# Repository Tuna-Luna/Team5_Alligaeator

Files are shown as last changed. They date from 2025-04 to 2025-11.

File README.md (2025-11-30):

# Alligaeator
## Capstone Design Project Team 5

## Overview
Alligaeator is an AI-powered nutrition assistant that combines a YOLOv5 food detector, an Arduino-driven load-cell scale, and an Android companion app. The system identifies a dish from a live webcam feed, measures its weight automatically, and reports calorie and macronutrient estimates through a mobile UI.

Design Overview

## Key Features
- Real-time food recognition powered by a custom-trained YOLOv5 model (`src/project/best2.pt`).
- Automated weight capture through an MG995 servo, HX711 load sensor, and Arduino firmware (`src/arduino/arduino.ino`).
- Nutrition lookup using per-gram macro data stored in `src/project/foods.json`, enabling instant calorie, carb, protein, and fat estimates.
- REST API built with FastAPI so the Android client (`src/application/MyApplication3.zip`) can request detections and control the hardware.
- Mechanical components and assembly-ready G-code/STL files (`3D/`) for the smart plate enclosure.

## Repository Tour
- `src/project/` – YOLOv5 inference utilities (`detect_api_final.py`), the FastAPI service (`android_respond_test.py`), dataset configs (`data.yaml`, `data2.yaml`), nutrition tables, and sample images (`food/`).
- `src/arduino/` – Arduino sketch that drives the MG995 servo, HX711 load cell, and optional I2C LCD for real-time weight display.
- `src/application/MyApplication3.zip` – Android Studio project that consumes the HTTP API and displays the nutrition report.
- `3D/` – Printable hinge, upper/lower plate, and enclosure parts in `.gcode`, `.3mf`, and `.stl` formats.
- `dataset.tar.gz` – Packaged training dataset used for YOLOv5 fine-tuning.
- `assets/` – Images and GIFs referenced in this README.

## System Architecture
The workflow starts with a webcam feed piped to a YOLOv5 model running on a Raspberry Pi or PC. Detected food classes are combined with real-time weight readings from the Arduino, and the FastAPI service exposes the combined nutrition information for the Android app.

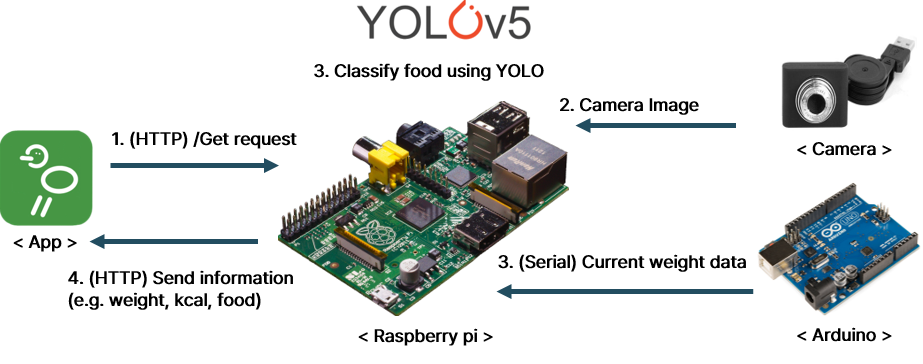
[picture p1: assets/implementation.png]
Implementation Overview


## Hardware System
The hardware layer mounts a plate on a load cell amplified by an HX711 module while an MG995 servo clears or rotates the plate between servings (`src/arduino/arduino.ino`). The Arduino publishes weight readings over serial (9600 baud) and accepts simple text commands (`LEFT`, `RIGHT`, `STOP`), which the FastAPI server issues when the Android app triggers plate rotation or resets the tare.

## Software Pipeline
### YOLOv5 Detector
`detect_api_final.py` wraps YOLOv5’s `DetectMultiBackend`, handles webcam capture, writes snapshots to `./captures/`, and returns the top detection (default `max_det=1`). Sample stills for offline testing live under `src/project/food/`.

### Nutrition + API Layer
`android_respond_test.py` hosts a FastAPI service that:
- calls the detector with `best2.pt` to classify food from either `source=0` (webcam) or the static `food/` images,
- reads the current weight from the Arduino over `/dev/ttyACM0`,
- multiplies the weight by per-gram values stored in `foods.json`, and
- returns the totals to the Android app. The same service exposes `/rotate`, `/finish`, and `/init` endpoints for servo control.

### Android Client
The Android Studio project (`MyApplication3.zip`) hooks into the FastAPI endpoints, displays detection results, and records the calorie log directly on the phone.

### 3D Printable Enclosure
All mechanical components needed for the smart plate—upper/lower shell, hinge variants, and mounting plates—are available in the `3D/` folder as ready-to-print `.gcode` or editable `.3mf`/`.stl` files to reproduce the physical housing.

## Dataset & Training Notes
`data2.yaml` defines 15 labeled food categories (`bean sprouts`, `beef`, `chicken`, `egg`, `pork`, `garlic`, `green onion`, `kimchi`, `onion`, `potato`, `spam`, `banana`, `sweet potato`, `cherry tomato`, `chicken breast`). Training/validation images are expected in `../train/images` and `../valid/images`, respectively, and the archived dataset (`dataset.tar.gz`) mirrors those splits. Model fine-tuning follows the standard YOLOv5 workflow

## Demo
Watch the final demo to see the full workflow in action.

Final Demo

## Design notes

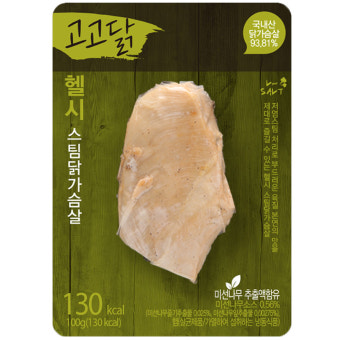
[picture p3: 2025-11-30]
src/project/food/cb2.jpg

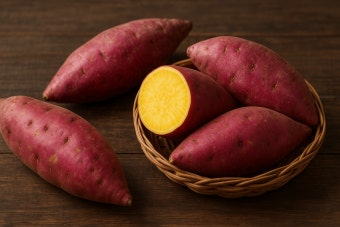
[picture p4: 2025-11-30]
src/project/food/sp3.jpg

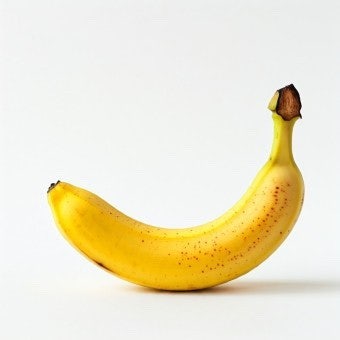
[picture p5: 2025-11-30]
src/project/food/b4.jpg

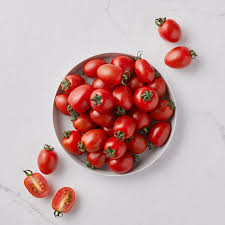
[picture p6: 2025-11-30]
src/project/food/ct2.jpg

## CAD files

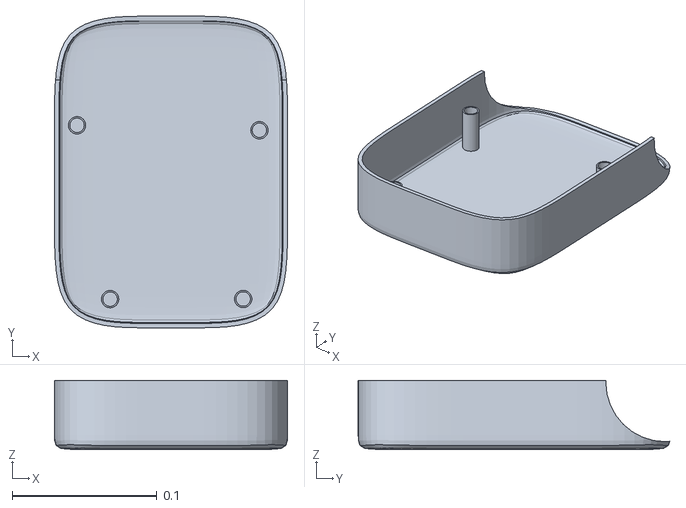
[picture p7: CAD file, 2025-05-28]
3D/하부_하부.stl
0.161 x 0.215 x 0.0478

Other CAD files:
3D/힌지Lver.3&힌지패드ver.1.gcode.3mf
3D/힌지L1.gcode.3mf
3D/힌지L2_힌지패드2.gcode.3mf
3D/힌지R.gcode.3mf
3D/힌지L&패드.gcode.3mf
3D/힌지_M&패드.gcode.3mf
3D/힌지_L.gcode.3mf
3D/하부_하부.gcode.3mf
3D/하부_입천장.gcode.3mf
3D/상부_입천장.gcode.3mf
3D/상부_상부.gcode.3mf
3D/힌지_R.gcode.3mf

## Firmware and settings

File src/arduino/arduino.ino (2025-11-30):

#include <Servo.h>
#include "HX711.h"
#include "LiquidCrystal_PCF8574.h"

// 서보모터 설정
Servo mg995;
const int servoPin = 10;
int currentAngle = 90;  // 현재 각도

// 로드셀 설정
const int DT_PIN = 6;
const int SCK_PIN = 5;
const float scale_factor = 434.16;
HX711 scale;

// LCD 설정 (원하면 사용 가능)
LiquidCrystal_PCF8574 lcd(0x27);  // 일반 주소 0x27 또는 0x3F

// 시리얼 명령 수신 버퍼
String command = "";

void setup() {
  Serial.begin(9600);
  Serial.println("Initializing the scale");

  // 서보 초기화
  mg995.attach(servoPin);
  mg995.write(currentAngle);

  // 로드셀 초기화
  scale.begin(DT_PIN, SCK_PIN);

  // LCD 초기화 (필요 시 주석 해제)
  lcd.begin(16, 2);
  lcd.setBacklight(255);
  lcd.clear();

  Serial.println("Before setting up the scale:");
  Serial.println(scale.get_units(5), 0);  // 설정 전 값 출력

  scale.set_scale(scale_factor);         // 스케일 설정
  scale.tare();                          // 영점 보정

  Serial.println("After setting up the scale:");
  Serial.println(scale.get_units(5), 0);  // 설정 후 값 출력

  Serial.println("System Ready. Type LEFT / RIGHT / STOP.");
}

void loop() {
  // -----------------------------
  // 1. 무게 측정 및 출력
  // -----------------------------
  float weight = scale.get_units(10);
  if (weight <= 0) weight = 0;

  // 정수만 출력
  Serial.println(round(weight));

  // LCD 출력 (원하면 사용 가능)
  // lcd.clear();
  // lcd.setCursor(0, 0);
  // lcd.print("Weight:");
  // lcd.setCursor(0, 1);
  // lcd.print(round(weight));
  // lcd.print(" g");

  scale.power_down();
  delay(500);
  scale.power_up();

  // -----------------------------
  // 2. 시리얼 명령 처리
  // -----------------------------
  while (Serial.available()) {
    char c = Serial.read();
    if (c == '\n' || c == '\r') {
      if (command.length() > 0) {
        handleCommand(command);
        command = "";
      }
    } else {
      command += c;
    }
  }
}

// -----------------------------
// 명령 처리 함수
// -----------------------------
void handleCommand(String cmd) {
  cmd.trim();

  if (cmd == "LEFT") {
    //currentAngle = constrain(currentAngle - 45, 0, 180);
    mg995.write(50);
    delay(600);  //각도를 시간으로 조절
    mg995.write(70);
    delay(500);
    mg995.write(90);
    currentAngle = 90;
  }
  else if (cmd == "RIGHT") {
    //currentAngle = constrain(currentAngle + 45, 0, 180);
    mg995.write(150);
    delay(1390);  //각도를 시간으로 조절
    mg995.write(100);
    delay(1300);
    mg995.write(90);
    //scale.tare();
    //currentAngle = 90;
  }
  else if (cmd == "STOP") {
    mg995.write(90);
    currentAngle = 90;
    scale.tare();
  }

  // Serial.print("ACK: ");
  // Serial.println(cmd);
}

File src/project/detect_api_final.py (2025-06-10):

import torch
import cv2
import tempfile
import os
from pathlib import Path
from models.common import DetectMultiBackend
from utils.general import non_max_suppression, scale_boxes
from utils.torch_utils import select_device
from utils.dataloaders import LoadImages
from typing import List, Optional, Dict, Any

def detect_objects(
    weights: str,
    source: str,
    data: str = './data2.yaml',
    imgsz: tuple = (640, 640),
    conf_thres: float = 0.25,
    iou_thres: float = 0.45,
    device: str = '',
    classes: Optional[List[int]] = None,
    max_det: int = 1,
    temp_img_save_path: Optional[str] = None,  # <-- 추가
) -> List[List[Dict[str, Any]]]:
    """
    Run YOLOv5 inference and return detection results.
    If `source` is numeric (webcam), captures one frame, saves it as:
      - a NamedTemporaryFile for inference
      - and, if `temp_img_save_path` is given, also at that path permanently.
    """
    device = select_device(device)
    model = DetectMultiBackend(weights, device=device, dnn=False, data=data, fp16=False)
    stride, names, pt = model.stride, model.names, model.pt
    imgsz = (imgsz[0] - imgsz[0] % stride, imgsz[1] - imgsz[1] % stride)

    src = str(source)
    use_temp_image = src.isnumeric()
    if use_temp_image:
        # 1) 웹캠에서 프레임 읽기
        cap = cv2.VideoCapture(int(src))
        if not cap.isOpened():
            raise RuntimeError("Failed to open webcam")
        ret, frame = cap.read()
        cap.release()
        if not ret:
            raise RuntimeError("Failed to capture frame from webcam")

        # 2) NamedTemporaryFile 에 쓰기 (inference 용)
        with tempfile.NamedTemporaryFile(suffix=".jpg", delete=False) as tmp:
            temp_img_path = tmp.name
            cv2.imwrite(temp_img_path, frame)

        # 3) 추가 저장 경로가 있으면 그곳에도 쓰기
        if temp_img_save_path:
            # 폴더가 없으면 생성
            os.makedirs(os.path.dirname(temp_img_save_path), exist_ok=True)
            cv2.imwrite(temp_img_save_path, frame)

        source = temp_img_path

    # LoadImages 는 단일 이미지 .jpg 경로 처리
    dataset = LoadImages(source, img_size=imgsz, stride=stride, auto=pt)
    results: List[List[Dict[str, Any]]] = []

    for path, im, im0, vid_cap, _ in dataset:
        # 전처리
        im = torch.from_numpy(im).to(model.device)
        im = im.float() / 255.0
        if im.ndim == 3:
            im = im.unsqueeze(0)

        # 추론 + NMS
        pred = model(im, augment=False, visualize=False)
        pred = non_max_suppression(pred, conf_thres, iou_thres, classes, False, max_det=max_det)

        dets: List[Dict[str, Any]] = []
        for det in pred:
            if det is not None and len(det):
                det[:, :4] = scale_boxes(im.shape[2:], det[:, :4], im0.shape).round()
                for *xyxy, conf, cls in det:
                    cls_id = int(cls)
                    dets.append({
                        'class_id': cls_id,
                        'name': names[cls_id],
                        'confidence': float(conf)
                    })
        results.append(dets)

    # NamedTemporaryFile 은 delete=False 여서 수동 삭제가 필요할 수 있습니다.
    if use_temp_image and os.path.exists(temp_img_path):
        os.unlink(temp_img_path)

    return results

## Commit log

2025-04-15 이게진짜입니당
    [아랫입천장.gcode.3mf]
2025-05-06 Add files via upload
    2025.05.07
    10h 2m
    [상부_상부.gcode.3mf]
2025-05-06 Add files via upload
    상부_입천장
    1h 11m
    [상부_입천장.gcode.3mf]
2025-05-06 Add files via upload
    05.07
    하부_입천장&상부_힌지패드
    1h 55m
    [하부_입천장&상부_힌지패드.gcode.3mf]
2025-05-06 Add files via upload
    하부_하부&상부_눈
    3h 45m
    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
    [하부_하부&상부_눈.gcode.3mf]
2025-05-07 Add files via upload
    힌지_힌지M&R&L
    6h 26m
    [힌지_M&R&L.gcode.3mf]
2025-05-26 Add files via upload
    블랜더 원본 파일
    블랜더 프로그램/3D뷰어/3D그림판/autodesk fusion 으로 확인 가능
2025-05-26 Add files via upload
    프린트 설정 방법
    연달아서 프린트해야 하는 파일 있으니 주의할 것!!
    [프린트_설정.xlsx]
